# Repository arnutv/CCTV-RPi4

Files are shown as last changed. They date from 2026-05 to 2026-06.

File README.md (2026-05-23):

# CCTV-RPi4

A complete, self-hosted DIY CCTV system using **6 ESP32-CAM modules** and a **Raspberry Pi 4 or 5** as a local WiFi hub, recorder and dashboard. No cloud, no subscriptions, no router required.





---

## What it does

- **6 wireless cameras** stream MJPEG to a local Raspberry Pi
- **Motion detection** on each ESP32-CAM triggers recording (saves to RPi storage **and** each camera's local SD card simultaneously)
- **Web dashboard** accessible from any phone or laptop — 3×2 live grid, click any camera to enlarge
- **HDMI monitor** mode — Pi shows a fullscreen 3×2 grid directly on a TV (Chromium kiosk on RPi ≥ 2 GB, native pygame on RPi 1 GB)
- **Solar-powered cameras** — each camera runs on a 6V/10W panel + 2× 18650 batteries (~$27 hardware)
- **3D-printed enclosure** — parametric OpenSCAD & FreeCAD designs included
- **Adaptive install** — one script auto-detects RAM and configures the system optimally (LITE / MID / FULL modes)
- **Optional internet bridge** — `connect_router.sh` lets the RPi share your home WiFi or ethernet with the cameras

---

## Architecture

```
   ┌──────────────┐   ┌──────────────┐   ┌──────────────┐
   │ ESP32-CAM #1 │   │ ESP32-CAM #2 │   │ ESP32-CAM #N │
   │  + SD card   │   │  + SD card   │   │  + SD card   │
   │  + solar/bat │   │  + solar/bat │   │  + solar/bat │
   └──────┬───────┘   └──────┬───────┘   └──────┬───────┘
          │ MJPEG @ port 81  │                  │
          │ + frame uploads  │                  │
          └─────────┬────────┴──────────────────┘
                    │  WiFi 192.168.4.0/24 (WPA2)
                    ▼
         ┌──────────────────────────┐
         │   Raspberry Pi 4 or 5    │
         │   wlan0 = AP (.4.1)      │
         │   Flask server :8080     │
         │   ├─ /         dashboard │
         │   ├─ /display  HDMI grid │
         │   ├─ /upload   from cams │
         │   └─ /api/cameras …      │
         └──┬──────────────────┬────┘
            │ HDMI             │ optional eth0 / wlan1
            ▼                  ▼
        ┌──────┐          ┌──────────────┐
        │  TV  │          │  Home router │
        └──────┘          │  → Internet  │
                          └──────────────┘
```

---

## Hardware

### Per camera (6× total)

| Item | Spec | ~Cost |
|---|---|---|
| AI-Thinker ESP32-CAM | OV2640 sensor, ESP32-S | $8 |
| MicroSD card | 16-32 GB Class 10 | $8 |
| 6 V 10 W solar panel | 250×200 mm | $9 |
| CN3791 MPPT charger | 1S Li-ion output | $3 |
| 2× 18650 Li-ion | Samsung 30Q or similar (3000 mAh) | $8 |
| 1S BMS module | DW01A+FS8205A, 20×10 mm (over-discharge + short-circuit) | $1 |
| MT3608 boost converter | 5 V output | $1 |
| IP65 junction box | 158×90×65 mm | $6 |
| Misc (PG7 gland, lens disc, screws) | | ~$3 |
| **Subtotal per camera** | | **~$47** |

### Hub

| Item | Spec | ~Cost |
|---|---|---|
| Raspberry Pi 4 (1 GB+) or RPi 5 (2 GB+) | | $35-50 |
| Power supply | 5V/3A USB-C (Pi 4) or 5V/5A (Pi 5) | $8-13 |
| MicroSD (or USB SSD) | 32 GB+ for OS + recordings | $8 |
| Active cooler | RPi 5 only | $5 |
| micro-HDMI cable | optional, for TV display | $5 |

**Total system cost: ~$330 for 6 cameras + hub.**

---

## Quick start

### 1. Raspberry Pi setup (15 min)

Flash **Raspberry Pi OS 64-bit (Bookworm)** to your SD card with Raspberry Pi Imager. Set hostname, enable SSH, configure your wifi for first-time access.

SSH in and run:

```bash
git clone https://github.com/arnutv/CCTV-RPi4.git
cd CCTV-RPi4/rpi4
sudo bash install.sh
sudo reboot
```

The installer **auto-detects** your board and RAM, then chooses:

| Mode | Trigger | What runs |
|---|---|---|
| **LITE** | RAM < 1.5 GB | Headless, native pygame HDMI display, `gpu_mem=32` |
| **MID** | RAM 1.5-3 GB | Chromium kiosk (trimmed), `gpu_mem=64` |
| **FULL** | RAM ≥ 4 GB | Full Chromium kiosk, `gpu_mem=128` |

After reboot:
- WiFi network **`CCTV_Network`** (pass: `cctv1234!!`) — cameras join this
- Dashboard at **`http://192.168.4.1:8080/`** from phone or laptop
- HDMI shows the 3×2 grid automatically (if connected)

### 2. Flash the cameras (5 min each)

For each ESP32-CAM, edit `CCTV-Camera/cam_config.h` to set its ID and name:

```cpp
#define CAM_ID   1                  // 1-6, unique per camera
#define CAM_NAME "Front Door"       // shown in dashboard
```

Open `CCTV-Camera/CCTV-Camera.ino` in Arduino IDE:
- Board: **AI Thinker ESP32-CAM**
- ESP32 core: **1.0.6** (pinned for stability)
- Partition: **Huge APP (3MB No OTA / 1MB SPIFFS)**

Flash with a USB-to-serial adapter (GPIO0 to GND while pressing reset).

> **Tip:** the included [GitHub Actions workflow](.github/workflows/build-firmware.yml) builds the firmware in the cloud — no Arduino IDE needed. Just go to the Actions tab → "Build ESP32-CAM Firmware" → Run workflow, fill in the cam ID/name, and download the `.bin` from the artifacts.

### 3. Power & mount the cameras

Connect each camera to its solar panel + 18650 battery rig (see `enclosure/wiring.txt`). Power on — the camera auto-connects to `CCTV_Network`, gets its static IP (`192.168.4.10X` based on `CAM_ID`), and appears live on the dashboard.

---

## Web dashboard

Browse to `http://192.168.4.1:8080/` from any device on the CCTV WiFi:

- **3×2 live grid** of all cameras with status pills (LIVE / MOTION / OFFLINE)
- **Click any camera** to enlarge to a large modal with live feed, battery %, and snapshot/page buttons
- **Recordings browser** with per-camera tabs, frame-by-frame playback, save individual frames
- **Storage chips** show RPi disk free + estimated days of retention left + auto-cleanup setting
- **One-click cleanup** button to flush recordings older than the retention period (default 30 days)
- **System health** in the header: CPU temp, uptime, internet IP (if connected), disk bar

---

## HDMI display

Plug an HDMI monitor or TV into the RPi (micro-HDMI to HDMI cable for RPi 4/5).

| Mode | Renderer | RAM cost | Notes |
|---|---|---|---|
| **LITE** | `display.py` — pygame on KMSDRM | ~80 MB | Auto-installed by `install.sh` on 1 GB boards; no X server, no browser |
| **MID/FULL** | Chromium kiosk → `/display` | ~500 MB | Same look as the web dashboard, GPU-accelerated |

Exit display: `Esc` or `Q` on a keyboard, or `sudo systemctl stop cctv-display`.

---

## Optional: internet bridge

By default the RPi is an island — cameras can talk to it but not to the internet. To bridge:

```bash
# Via ethernet (cleanest)
sudo bash rpi4/connect_router.sh eth

# Via USB WiFi dongle
sudo bash rpi4/connect_router.sh wifi "HomeWiFi" "yourpassword"

# Undo
sudo bash rpi4/connect_router.sh --remove
```

Now the dashboard is also reachable from your home network (look for the IP in the dashboard header), and you can SSH in from anywhere on your LAN.

---

## Enclosure & 3D printing

Files in `enclosure/` — two formats, each part also has its own standalone file:

| File | Contents |
|---|---|
| `tray.scad` | Electronics tray — open, F6, export STL |
| `solar_bracket.scad` | Solar panel arm — open, F6, export STL |
| `cctv_enclosure.scad` | Both parts in one file (`PART = "all"` preview) |
| `cctv_enclosure.FCMacro` | FreeCAD Python macro — same 2 parts |

Designed to drop inside a **140 × 78 mm outer IP65 junction box** (typical thai weatherproof box). The lens hole and ESP32-CAM mount are drilled directly through the box's own lid.

Parts (3D-printed):

| Part | File | Print time | Filament | Purpose |
|---|---|---|---|---|
| Electronics tray | `tray.scad` | 90 min | 28 g | Holds battery + MPPT + boost inside the IP65 box |
| Solar bracket | `solar_bracket.scad` | 55 min | 20 g | L-arm screws to wall (2× M5); solar panel bolts to far end of arm (4× M4) |

**Print in PETG** (or ASA) at 0.2 mm, 4 perimeters, 25 % gyroid infill. No supports needed.

See `enclosure/wiring.txt` for the full assembly + waterproofing checklist.

---

## File layout

```
CCTV-RPi4/
├── CCTV-Camera/                 # Arduino sketch (flash this to each ESP32-CAM)
│   ├── CCTV-Camera.ino
│   ├── cam_config.h            # ← Edit CAM_ID and CAM_NAME per unit
│   ├── camera_pins.h
│   ├── motion.h
│   ├── power.h
│   ├── recorder.h
│   └── webui.h
├── rpi4/                        # Raspberry Pi server side
│   ├── install.sh              # One-shot setup (auto-adaptive LITE/MID/FULL)
│   ├── cctv_server.py          # Flask dashboard + upload endpoint
│   ├── display.py              # Native pygame HDMI display (LITE mode)
│   └── connect_router.sh       # Optional internet bridge
├── preview/                     # Browser preview of the dashboard (Windows PC)
│   ├── index.html              # Static mock dashboard
│   └── serve.ps1               # Tiny PowerShell HTTP server
├── enclosure/                   # 3D-printable parts
│   ├── tray.scad               # Electronics tray — standalone, open → F6 → STL
│   ├── solar_bracket.scad      # Solar panel arm  — standalone, open → F6 → STL
│   ├── cctv_enclosure.scad     # Combined preview (both parts, PART variable)
│   ├── cctv_enclosure.FCMacro  # FreeCAD Python macro (same 2 parts)
│   └── wiring.txt              # ASCII wiring + waterproofing notes
├── .github/workflows/
│   └── build-firmware.yml      # Cloud-builds ESP32 firmware, exports .bin
├── .gitignore
└── README.md
```

---

## Configuration cheatsheet

| What | Where | Default |
|---|---|---|
| WiFi SSID + password | `CCTV-Camera/cam_config.h` + `rpi4/install.sh` | `CCTV_Network` / `cctv1234!!` |
| Camera ID + name | `CCTV-Camera/cam_config.h` per unit | `CAM_ID 1`, `"Front Door"` |
| RPi static IP for AP | `rpi4/install.sh` | `192.168.4.1` |
| Recording retention | `rpi4/cctv_server.py` → `RETENTION_DAYS` | `30` days |
| Frame resolution | inside `CCTV-Camera.ino`: `s->set_framesize()` | `FRAMESIZE_VGA` |
| GPU memory | auto via install.sh | 32/64/128 MB |
| Server port | `rpi4/cctv_server.py` | `8080` |
| Cameras list (for dashboard) | `rpi4/cctv_server.py` → `CAMERAS` | 6 entries, edit to add/remove |

---

## Performance

Measured with **6 cameras at VGA 5 FPS, motion-triggered recording**:

| Board | Boot | CPU idle | CPU peak | RAM used | Smoothness |
|---|---|---|---|---|---|
| RPi 4 1 GB | ~25 s | 4 % | 35-45 % | ~600 MB | Adequate |
| RPi 4 2/4/8 GB | ~22 s | 3 % | 25-35 % | ~600 MB | Smooth |
| RPi 5 (2/4/8 GB) | ~12 s | 1-2 % | 12-18 % | ~700 MB | Snappy |

Cameras can scale up to **~12 units** before grid cells become too small to read on a 32" TV.

---

## Troubleshooting

| Symptom | Likely cause | Fix |
|---|---|---|
| Camera shows OFFLINE in dashboard | Bad wifi / wrong CAM_ID | Re-flash with correct config; check serial output |
| Dashboard slow / laggy | Too many concurrent viewers | Max 2-3 phones streaming full grid; close extras |
| Recordings folder filling disk | Retention too long | Lower `RETENTION_DAYS` and run "Clean now" |
| HDMI black on RPi 5 1 GB | Chromium ran out of memory | Confirm install picked LITE mode; check `systemctl status cctv-display` |
| Solar camera dies overnight | Cloudy days drained battery | Upsize to 12 V 20 W panel + LiFePO4 (see `wiring.txt` "Robust tier") |
| Lens fogged from inside | Trapped condensation | Add a PTFE breathable vent on the bottom of the IP65 box |

---

## Contributing

PRs welcome. Run the cloud build (Actions tab) before opening a PR to confirm the firmware still compiles.

---

## License

MIT — see [LICENSE](LICENSE) if present, otherwise consider this MIT-licensed.

---

## Credits

Built with `esp32-arduino`, `esp_camera`, `Flask`, `pygame`, `hostapd`, `dnsmasq` and a Raspberry Pi.

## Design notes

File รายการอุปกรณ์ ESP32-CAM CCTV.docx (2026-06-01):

รายการอุปกรณ์ ESP32-CAM CCTV

Solar Cell 6V 15W + CN3791 MPPT Charge Controller

วันที่: 23 พฤษภาคม 2026

1. หลัก / Main Components

1. ESP32-CAM AI-Thinker - With OV2640 Camera Module x1 232.46 GusTron

2. Solar Panel - 6V 15W x1 236.15 ณ ภัทร เทคโนโลยี

3. CN3791 MPPT Charge Controller - 4.5V-6V Input, 1-2A (Module) x1 91.77 ไอ.อาร์. เทคโนโลยี

4. 18650 Li-ion Battery - 3000-3500 mAh x2 27.00 Exceedbytech

5. 18650 Battery Holder - 2-Cell Parallel x1 n/a

6. MT3608 Boost Converter - 3.7V to 5V Output x1 72.46/3 ไอ.อาร์. เทคโนโลยี

7. MicroSD Card - 16GB+ Class 10 x1 n/a

8. USB-TTL Programmer - CH340 or FTDI Module x1 n/a

9. Waterproof Enclosure Box - IP65+ x1 75.00/3 NNR Home Solution

รวม 636.53

2. อุปกรณ์เสริม / Supporting Components

9. Resistor - 100k Ohm x2

10. Capacitor - 100uF 10V x1

11. Capacitor - 10uF 10V x1

12. Inductor - 10uH (สำหรับ CN3791 แบบ DIY) x1

13. Diode Schottky - 1N5819 x1

14. Waterproof Enclosure Box - IP65+ x1

15. Cable Gland - PG7 x2

16. JST Connector / Screw Terminal- - 1 ชุด

17. Jumper Wire / PCB Stripboard - - 1 ชุด

3. วงจรไฟ / Power Flow

Solar Panel 6V 15W

CN3791 MPPT <--> 2x 18650 (parallel)

(ใช้พลังงานเต็ม 15W)

MT3608 Boost Converter

5V ESP32-CAM

GPIO33 <-- Voltage Divider (100k+100k) <-- Battery+

4. CN3791 vs TP4056 เปรียบเทียบ

ชาร์จสูงสุด : TP4056 = 1A | CN3791 = 2A

MPPT : TP4056 = ไม่มี | CN3791 = มี

ใช้พลังงาน Panel : TP4056 = ~40% | CN3791 = ~95%

ราคา : TP4056 = ถูก | CN3791 = แพงกว่านิดหน่อย

ต้องการ Inductor : TP4056 = ไม่ | CN3791 = ใช่ (ถ้า DIY)

5. หมายเหตุ / Notes

* CN3791 แบบ Module สำเร็จรูป มี Inductor และ Diode ติดมาแล้ว แนะนำซื้อแบบ Module

* TP4056 ชาร์จได้สูงสุด 1A แม้ Panel จะให้ 2.5A ทำให้เสียพลังงาน ~60%

* CN3791 ใช้ MPPT ดึงพลังงานจาก Panel ได้เกือบ 100%

* 2x 18650 ต่อ Parallel ให้ความจุรวม ~6000-7000 mAh รองรับกลางคืน ~20-23 ชั่วโมง

* MT3608 Boost Converter แปลง 3.7V (แบต) เป็น 5V สำหรับ ESP32-CAM

* GPIO33 + Voltage Divider (100k+100k) ใช้วัดระดับแบตเตอรี่ใน firmware

* แนะนำ MicroSD Class 10 ขึ้นไป รองรับการบันทึก JPEG ต่อเนื่อง ~5fps

สร้างโดย Claude Code | ESP32-CAM CCTV Project | 23 พฤษภาคม 2026

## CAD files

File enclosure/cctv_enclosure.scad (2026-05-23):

// ═══════════════════════════════════════════════════════════════════════════
//  CCTV-Camera — Enclosure parts (combined preview file)
//  For single-part STL export use the individual files:
//    tray.scad           — Electronics tray  (open → F6 → Export STL)
//    solar_bracket.scad  — Solar panel arm   (open → F6 → Export STL)
//
//  This file lets you preview both parts together or pick one with PART.
//  All dimensions in mm. Print in PETG (preferred) or PLA+.
// ═══════════════════════════════════════════════════════════════════════════

// ─── PICK ONE PART TO RENDER ──────────────────────────────────────────────
PART = "all";   // "tray" | "solar_bracket" | "all"

// ─── IP65 BOX INNER DIMENSIONS ────────────────────────────────────────────
BOX_W = 134;   // inside width  (140 mm outer − 2×3 mm walls)
BOX_D =  72;   // inside depth  ( 78 mm outer − 2×3 mm walls)

// ─── ELECTRONICS (real measured sizes, mm) ────────────────────────────────
HOLDER_W = 75;  HOLDER_D = 36;
CN3791_W = 30;  CN3791_D = 20;
MT3608_W = 36;  MT3608_D = 17;
BMS_W    = 20;  BMS_D    = 10;   // 1S BMS (DW01A+FS8205A, 20×10 mm)

// ─── SOLAR BRACKET ────────────────────────────────────────────────────────
ARM_L   = 80;
ARM_W   = 25;
ARM_TH  =  4;
PLATE_H = 100;

// ─── PRINT TOLERANCES ─────────────────────────────────────────────────────
WALL = 1.6;
SLOP = 0.3;
$fn = 64;

// ═══════════════════════════════════════════════════════════════════════════
//                                 PARTS
// ═══════════════════════════════════════════════════════════════════════════

// ─── Helper: PCB clip ─────────────────────────────────────────────────────
module pcb_clip(pcb_w, pcb_d, h) {
    difference() {
        cube([pcb_w + WALL*2 + SLOP*2, pcb_d + WALL*2 + SLOP*2, h]);
        translate([WALL, WALL, 1.6])
            cube([pcb_w + SLOP*2, pcb_d + SLOP*2, h]);
        translate([(pcb_w + WALL*2)/2 - 6, -1, 3])
            cube([12, pcb_d + WALL*4 + SLOP*2 + 2, h]);
    }
}

// ─── 1. ELECTRONICS TRAY ──────────────────────────────────────────────────
module electronics_tray() {
    difference() {
        union() {
            cube([BOX_W - 4, BOX_D - 4, 2]);

            translate([4, 4, 2])
                difference() {
                    cube([HOLDER_W + SLOP*2, HOLDER_D + SLOP*2, 8]);
                    translate([WALL, WALL, 2])
                        cube([HOLDER_W + SLOP*2 - WALL*2,
                              HOLDER_D + SLOP*2 - WALL*2, 10]);
                }

            // Right column: MPPT (top) → Boost (middle) → BMS (bottom)
            translate([4 + HOLDER_W + 6, 4, 2])
                pcb_clip(CN3791_W, CN3791_D, 6);

            translate([4 + HOLDER_W + 6, 4 + CN3791_D + 5, 2])
                pcb_clip(MT3608_W, MT3608_D, 6);

            translate([4 + HOLDER_W + 6, 4 + CN3791_D + 5 + MT3608_D + 5, 2])
                pcb_clip(BMS_W, BMS_D, 6);

            for (x = [10, BOX_W - 14], y = [10, BOX_D - 14])
                translate([x, y, 2]) cylinder(d=4, h=12);
        }

        for (x = [6, BOX_W - 10], y = [6, BOX_D - 10])
            translate([x, y, -1]) cylinder(d=3.4, h=5);
    }
}

// ─── 2. SOLAR BRACKET ─────────────────────────────────────────────────────
module solar_bracket() {
    // Vertical wall plate
    difference() {
        cube([ARM_W, ARM_TH, PLATE_H]);
        for (z = [15, PLATE_H - 15]) {
            translate([ARM_W/2, -1, z])
                rotate([-90, 0, 0])
                    cylinder(d=5.5, h=ARM_TH + 2);
            translate([ARM_W/2, -0.1, z])
                rotate([-90, 0, 0])
                    cylinder(d1=10.5, d2=5.5, h=3.2);
        }
    }

    // Horizontal arm
    translate([0, ARM_TH, PLATE_H - ARM_TH])
        difference() {
            cube([ARM_W, ARM_L, ARM_TH]);
            // 4× M4 panel mounting holes near far end
            for (xp = [5, ARM_W - 5], yp = [ARM_L - 20, ARM_L - 8])
                translate([xp, yp, -1])
                    cylinder(d=4.5, h=ARM_TH + 2);
        }

    // Triangular gusset
    translate([0, ARM_TH, PLATE_H - ARM_TH])
        rotate([0, -90, 0])
            linear_extrude(ARM_W)
                polygon([[0, 0], [25, 0], [0, -25]]);
}

// ═══════════════════════════════════════════════════════════════════════════
//                            LAY OUT FOR EXPORT
// ═══════════════════════════════════════════════════════════════════════════
if      (PART == "tray")           electronics_tray();
else if (PART == "solar_bracket")  solar_bracket();
else {
    // "all" — both parts side by side for preview
    electronics_tray();
    translate([BOX_W + 30, 0, 0]) solar_bracket();
}

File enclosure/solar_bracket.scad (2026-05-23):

// ═══════════════════════════════════════════════════════════════════════════
//  Solar Bracket  —  standalone part file
//  L-shaped wall arm for mounting a 6V/10W solar panel.
//
//  Geometry:
//    Vertical wall plate  25 × 4 × 100 mm   — screws to wall (2× M5)
//    Horizontal arm       25 × 80 × 4 mm    — panel rests on top
//    Triangular gusset                       — prevents arm from drooping
//    Panel mounting holes  4× M4 at arm end — bolts through panel frame
//
//  Open in OpenSCAD → F6 → File → Export → STL
//  Print in PETG (preferred for UV/outdoor) at 0.2 mm layers,
//  4 perimeters, 40 % gyroid infill. No supports needed.
// ═══════════════════════════════════════════════════════════════════════════

ARM_L   = 80;    // horizontal arm length (mm)
ARM_W   = 25;    // arm + plate width     (mm)
ARM_TH  =  4;    // arm + plate thickness (mm)
PLATE_H = 100;   // vertical plate height (mm)

$fn = 64;

module solar_bracket() {
    // ── Vertical wall plate ──────────────────────────────────────────────
    difference() {
        cube([ARM_W, ARM_TH, PLATE_H]);
        // 2× M5 wall-screw holes (⌀5.5), countersunk on the back face
        for (z = [15, PLATE_H - 15]) {
            translate([ARM_W/2, -1, z])
                rotate([-90, 0, 0])
                    cylinder(d=5.5, h=ARM_TH + 2);
            translate([ARM_W/2, -0.1, z])
                rotate([-90, 0, 0])
                    cylinder(d1=10.5, d2=5.5, h=3.2);   // 90° countersink
        }
    }

    // ── Horizontal arm (extends outward from top of plate) ───────────────
    translate([0, ARM_TH, PLATE_H - ARM_TH])
        difference() {
            cube([ARM_W, ARM_L, ARM_TH]);
            // 4× M4 panel mounting holes (⌀4.5) near the far end of arm
            for (xp = [5, ARM_W - 5], yp = [ARM_L - 20, ARM_L - 8])
                translate([xp, yp, -1])
                    cylinder(d=4.5, h=ARM_TH + 2);
        }

    // ── Triangular gusset (joins underside of arm to plate) ─────────────
    translate([0, ARM_TH, PLATE_H - ARM_TH])
        rotate([0, -90, 0])
            linear_extrude(ARM_W)
                polygon([[0, 0], [25, 0], [0, -25]]);
}

solar_bracket();

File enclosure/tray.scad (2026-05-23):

// ═══════════════════════════════════════════════════════════════════════════
//  Electronics Tray  —  standalone part file
//  Sits inside the IP65 junction box and holds battery + MPPT + boost
//  converter + BMS in fixed positions (no rattling).
//
//  Circuit flow:
//    Solar → CN3791 (MPPT charge) → 18650 × 2 → BMS (discharge protect)
//    → MT3608 (boost 5 V) → ESP32-CAM
//
//  Open in OpenSCAD → F6 → File → Export → STL
//  Print in PETG (preferred) or PLA+ at 0.2 mm layers, 4 perimeters,
//  25 % gyroid infill. No supports needed.
// ═══════════════════════════════════════════════════════════════════════════

// ─── IP65 BOX INNER DIMENSIONS ────────────────────────────────────────────
// Default for 140 × 78 mm outer junction box (typical thai weatherproof box):
//   140 - 2×3 mm walls = 134 mm inner length
//    78 - 2×3 mm walls =  72 mm inner depth
// Edit to match your box (always use INNER measurements).
BOX_W = 134;   // inside width  (lengthwise)
BOX_D =  72;   // inside depth  (top → bottom mounted)

// ─── ELECTRONICS (real measured sizes, mm) ────────────────────────────────
HOLDER_W = 75;  HOLDER_D = 36;   // 2× 18650 battery holder footprint
CN3791_W = 30;  CN3791_D = 20;   // CN3791 MPPT charger PCB
MT3608_W = 36;  MT3608_D = 17;   // MT3608 boost converter PCB
BMS_W    = 20;  BMS_D    = 10;   // 1S BMS module (DW01A+FS8205A, 20×10 mm)

// ─── PRINT TOLERANCES ─────────────────────────────────────────────────────
WALL = 1.6;   // wall thickness (4 perimeters @ 0.4 mm nozzle)
SLOP = 0.3;   // fit clearance
$fn = 64;

// Column X offset shared by MPPT, Boost, BMS clips
COL_X = 4 + HOLDER_W + 6;   // = 85 mm from tray left edge

// ═══════════════════════════════════════════════════════════════════════════

// PCB clip — two L-shaped fingers that grip a small PCB by its edges.
// A centre window lets you lift the PCB out without tools.
module pcb_clip(pcb_w, pcb_d, h) {
    difference() {
        cube([pcb_w + WALL*2 + SLOP*2, pcb_d + WALL*2 + SLOP*2, h]);
        translate([WALL, WALL, 1.6])
            cube([pcb_w + SLOP*2, pcb_d + SLOP*2, h]);
        translate([(pcb_w + WALL*2)/2 - 6, -1, 3])
            cube([12, pcb_d + WALL*4 + SLOP*2 + 2, h]);
    }
}

// Main tray
module electronics_tray() {
    difference() {
        union() {
            // Base plate
            cube([BOX_W - 4, BOX_D - 4, 2]);

            // Battery holder pocket (open box around holder, left side)
            translate([4, 4, 2])
                difference() {
                    cube([HOLDER_W + SLOP*2, HOLDER_D + SLOP*2, 8]);
                    translate([WALL, WALL, 2])
                        cube([HOLDER_W + SLOP*2 - WALL*2,
                              HOLDER_D + SLOP*2 - WALL*2, 10]);
                }

            // MPPT charger clip (right column, top)
            translate([COL_X, 4, 2])
                pcb_clip(CN3791_W, CN3791_D, 6);

            // Boost converter clip (right column, middle)
            translate([COL_X, 4 + CN3791_D + 5, 2])
                pcb_clip(MT3608_W, MT3608_D, 6);

            // BMS clip (right column, bottom — under boost)
            translate([COL_X, 4 + CN3791_D + 5 + MT3608_D + 5, 2])
                pcb_clip(BMS_W, BMS_D, 6);

            // Cable routing posts at 4 corners
            for (x = [10, BOX_W - 14], y = [10, BOX_D - 14])
                translate([x, y, 2]) cylinder(d=4, h=12);
        }

        // M3 screw holes (align with standoffs inside the IP65 box)
        for (x = [6, BOX_W - 10], y = [6, BOX_D - 10])
            translate([x, y, -1]) cylinder(d=3.4, h=5);
    }
}

electronics_tray();

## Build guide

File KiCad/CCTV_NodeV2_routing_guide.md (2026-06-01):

# CCTV_NodeV2 — PCB routing guide

The schematic (`CCTV_NodeV2.kicad_sch`) and the PCB (`CCTV_NodeV2.kicad_pcb`) are both checked in. The PCB has all 9 components placed on a 100 × 80 mm 2-layer board with **every net assigned to its correct pad**. What's missing are the **copper traces** — the colored airwires you see in pcbnew.

KiCad 10 ships **without a built-in autorouter**. You have two routes from "ratsnest" to "fully routed board":

| Path | Time | Quality | Effort |
|---|---|---|---|
| **A. Interactive routing in pcbnew** | 15–30 min | excellent | manual, learn the X tool |
| **B. Freerouting (external)** | 2–5 min | good, sometimes messy | one-time download |

---

## A. Interactive routing (recommended for small boards)

1. Open `KiCad/CCTV_NodeV2.kicad_pcb` in KiCad → pcbnew opens.
2. Press **`B`** to refresh the ratsnest — colored thin lines now connect pads that share a net.
3. Press **`X`** to start the **interactive router**.
4. Click a pad (or hover over a ratsnest line and click), drag, and click again to lay each segment. Press **`V`** to drop a via to the other copper layer when you need to cross a trace.
5. Press **`Esc`** to finish a route, then click the next net.
6. When all airwires are gone you're done. **Run DRC** (`Inspect → Design Rules Checker`) to catch any clearance issues.

Order I'd recommend:
- **Power first** (`+5V`, `+3V3`, `BATT+`, `GND`, `SOLAR+/-`, `BATT-`, `PROT-` — wait, this PCB consolidates to `GND`)
- **Camera control** next (`SIOC`, `SIOD`, `VSYNC`, `HREF`, `PCLK`, `XCLK`)
- **Camera data bus last** (`CAM_D0..D7`) — these are the 8 lines that run from U4 right side to U5 right side; expect to use a couple of vias to drop through the board

---

## B. Freerouting (one-click autorouter)

### One-time setup

1. **Install Java 17 or later** if you don't have it. Test with `java -version` in a terminal — should print something with `17.x` or higher.
   - Windows: download the LTS JDK from https://adoptium.net/
2. **Download Freerouting**:
   - Go to https://github.com/freerouting/freerouting/releases
   - Grab the latest `freerouting-X.Y.Z.jar`
   - Save it somewhere stable, e.g. `C:\Tools\freerouting.jar`

### Each time you want to autoroute

1. In pcbnew with `CCTV_NodeV2.kicad_pcb` open:
   - **File → Export → Specctra DSN…**
   - Save as `CCTV_NodeV2.dsn` next to your PCB file.
2. Open a terminal in the same folder and run:
   ```powershell
   java -jar C:\Tools\freerouting.jar -de CCTV_NodeV2.dsn -do CCTV_NodeV2.ses
   ```
   - `-de` = design (input)
   - `-do` = output session
   - Freerouting will route in headless mode for a few minutes; you'll see progress in the terminal. For interactive mode (GUI), drop the `-do` flag.
3. Back in pcbnew:
   - **File → Import → Specctra Session…**
   - Pick `CCTV_NodeV2.ses`. KiCad lays down all the traces.
4. Press **`B`** to refresh ratsnest — there should be no airwires left.
5. **Run DRC** to verify clearance.

### If Freerouting struggles

- Add **net classes** before exporting: `File → Board Setup → Net Classes`. Make a "Power" class with wider traces (e.g. 0.5 mm) for `+5V`, `+3V3`, `BATT+`, `GND`, and keep default (~0.25 mm) for signals.
- Increase board size: `Edit → Properties` of the Edge.Cuts rectangle, expand to 110 × 90 if needed.
- Re-run with the `-mp <passes>` flag for more optimization, e.g. `-mp 100`.

---

## Current component placement

The PCB ships with this layout. Move things in pcbnew (`M` key) if you don't like it — the routing happens after placement so you can always re-route.

| Ref | Component | Position (mm) | Rotation | Notes |
|---|---|---|---|---|
| J1 | Solar input (2-pin header) | (10, 12) | 90° | top-left, wires up to solar panel |
| U1 | CN3791 MPPT | (35, 12) | 0° | next to J1 |
| U2 | 1S BMS DW01A+FS8205A | (62, 12) | 0° | top-right of power chain |
| J2 | Battery pack connector (2-pin) | (10, 28) | 90° | left side, wires to 18650 pack |
| U3 | MT3608 boost | (62, 28) | 0° | below U2, +5V output goes south to U4 |
| R1 | 4.7 kΩ SIOD pull-up | (40, 38) | 90° | between MT3608 and U4 |
| R2 | 4.7 kΩ SIOC pull-up | (50, 38) | 90° | next to R1 |
| U4 | ESP32-S3-DevKitC-1 | (30, 55) | 0° | bottom-center, USB-C marker pointing up |
| U5 | OV7670 camera module | (70, 55) | 0° | bottom-right, lens marker at center |

Board outline: 0,0 to 100,80 mm rectangle on Edge.Cuts.

---

## What's already routed

The PCB ships **fully routed** — 96 trace segments covering all 21 nets:
- 18 power traces at 1 mm width on F.Cu (BATT+, BATT-, +5V, +3V3, SOLAR+, SOLAR-, partial GND)
- 38 signal + auxiliary power traces at 0.7 mm width on F.Cu (camera control + GND chain + J2 routes on B.Cu)
- 40 camera data traces at 0.7 mm width on B.Cu (CAM_D0..D7, 5 segments each in a switching pattern)

Open in pcbnew and press `B` — the ratsnest should be empty (no airwires).

| Net | Status | Notes |
|---|---|---|
| `SOLAR+` | ✅ done (1 mm F.Cu) | J1.1 → U1.1, diagonal |
| `SOLAR-` | ✅ done (1 mm F.Cu) | J1.2 → U1.2, 2-segment L |
| `BATT+` | ✅ done (1 mm F.Cu + 0.7 mm B.Cu) | Top rail at y=5 + J2.1 via left edge on B.Cu through y=8 |
| `BATT-` | ✅ done (1 mm F.Cu + 0.7 mm B.Cu) | U1.4 → U2.2 + J2.2 via left edge on B.Cu through y=16 |
| `+5V` | ✅ done (1 mm F.Cu) | U3.3 → U4.1 via right side and underbelly at y=40 |
| `+3V3` | ✅ done (1 mm + 0.7 mm F.Cu) | U4.3 → R1 → R2 → U5.1 (U4.3 exit via y=49.92 west-east then up around R1) |
| `GND` | ✅ done (0.7 mm F.Cu) | U2.4 → right edge (x=75) → U3.4 → down through OV7670 body → U5.2 + U5.4 bypass + U4.2 horizontal |
| Camera control: `SIOC`, `SIOD`, `VSYNC`, `HREF`, `PCLK`, `XCLK` | ✅ done (0.7 mm F.Cu) | Each routed as L-shape from U4 left column to U5 left column through inter-column gap |
| Camera data (`CAM_D0..D7`) | ✅ done (0.7 mm B.Cu) | All 8 lines routed on the back copper layer with a 5-segment switching pattern: exit U4 east, drop south to a unique bottom rail (y=68–76.4, 1.2 mm pitch), traverse east past U5, climb north to target y, into U5 right pad from the east. No vias needed (through-hole pads bridge layers). |

All nets are routed. If you want to verify or improve:
- Open in pcbnew, press `B` to refresh ratsnest — should be empty
- Run DRC (`Inspect → Design Rules Checker`) — expect ~6 clearance warnings at U4's right pad column (see DRC notes below)
- If desired, run Freerouting on the same DSN export — it will re-optimize the layout (typically tightening corners and reducing total trace length 10–20%)

### DRC notes for the hand-routed traces

Most traces pass between header pads at the standard 2.54 mm pitch. With 0.7 mm trace width + 1.7 mm pad diameter, the trace-to-pad clearance through the gap is **~0.07 mm** — KiCad's default 0.2 mm clearance rule will flag these.

To resolve, in **File → Board Setup → Constraints**:
- Set "Minimum clearance" to 0.1 mm (industry minimum for most fabs)
- Or reduce just the affected traces to 0.5 mm width and clearance stays at 0.2 mm
- Or accept the DRC violations if you're hand-soldering (the pads still fit, the traces just sit closer than the design rule prefers)

## Net summary (21 nets + GND)

Power: `SOLAR+`, `SOLAR-`, `BATT+`, `BATT-`, `GND`, `+5V`, `+3V3`
Camera I²C/control: `SIOD`, `SIOC`, `VSYNC`, `HREF`, `PCLK`, `XCLK`
Camera data: `CAM_D0`, `CAM_D1`, …, `CAM_D7`

> Note: the PCB consolidates the schematic's `PROT-` net into `GND` (they're electrically the same node — BMS P- and chip grounds tied together). If you re-run `Update PCB from Schematic` (F8), KiCad will flag this; either accept the merge or update the schematic to use `GND` everywhere downstream of the BMS.

---

## Manufacturing checklist (when ready)

- [ ] DRC passes (zero errors)
- [ ] Run `File → Plot…` → Gerbers + drill files
- [ ] Upload zip to JLCPCB / PCBWay / OSHPark
- [ ] Order 2-layer, 1.6 mm thickness, HASL or ENIG finish, standard FR-4
- [ ] Order matching stencil if you're doing reflow (not needed — all through-hole on this board)

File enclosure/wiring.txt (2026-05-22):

CCTV-Camera Wiring Diagram  (Recommended tier:  6V/10W panel + 2× 18650)
═══════════════════════════════════════════════════════════════════════════

                              ┌────────────────────┐
                              │   6V / 10W SOLAR   │
                              │   panel  (mounted  │
                              │   above box on     │
                              │   L-bracket)       │
                              └─────────┬──────────┘
                                        │  red(+) / black(−)
                                        │  ~30 cm cable
                                        │
                              [PG7 cable gland in box top]
                                        │
                                        ▼
                            ┌───────────────────────┐
                            │  CN3791 MPPT Charger  │
                            │   IN+   IN−   OUT+/−  │
                            │   ●─────●─────●──●    │
                            └───────────────────────┘
                                              │ │
                                              ▼ ▼
                            ┌───────────────────────┐
                            │  2× 18650 in PARALLEL │
                            │   3.0–4.2 V  6000 mAh │
                            │ (+) ────────────── (−)│
                            └───────────────────────┘
                                              │ │
                                              ▼ ▼
                            ┌───────────────────────┐
                            │  MT3608 Boost → 5 V   │
                            │   IN+   IN−   OUT+/−  │
                            │     adjust pot to 5.0V│
                            │     BEFORE connecting │
                            │     the ESP32!        │
                            └─────────┬─────────────┘
                                      │ 5 V  +  GND
                                      ▼
                            ┌───────────────────────┐
                            │     ESP32-CAM         │
                            │   5V  GND  U0R  U0T   │
                            │   ●   ●     ─   ─     │
                            │  (use 5V pin, NOT 3V) │
                            │                       │
                            │   SD card slot:       │
                            │   ┌───────┐           │
                            │   │ 16 GB │           │
                            │   └───────┘           │
                            └───────────────────────┘
                                      │
                                      └──→ Camera lens (front of box,
                                            sealed with O-ring + clear disc)

                            ┌───────────────────────┐
                            │   SMA antenna (side)  │
                            │   2.4 GHz 2 dBi omni  │
                            │   ↑ extends WiFi      │
                            │     range ~3×         │
                            └───────────────────────┘
                            (solder pigtail to ESP32-CAM
                             U.FL pad — see notes below)

WIRE GAUGE & LENGTHS
─────────────────────
  Solar → MPPT     :  20 AWG, 30 cm    (any colour, polarity matters)
  MPPT → Battery   :  20 AWG, 5 cm     (RED to +, BLACK to −)
  Battery → Boost  :  20 AWG, 5 cm
  Boost → ESP32    :  22 AWG, 8 cm     (twist pair to reduce noise)

OPTIONAL ADD-ONS
─────────────────────
  Power LED        :  3 mm green, 1 kΩ resistor, across 5 V rail.
                       Visible through 3 mm hole next to lens.
  Reset button     :  Tactile switch from ESP32-CAM RST to GND,
                       through a 6 mm waterproof button in the box side.
  Battery cut-off  :  1S BMS protection module BETWEEN battery and boost.
                       Stops over-discharge below 2.5 V (saves 18650 cells).
  External antenna :  Cut the 0Ω resistor on ESP32-CAM near U.FL connector
                       (re-route from PCB antenna to U.FL → SMA pigtail).

WATERPROOFING CHECKLIST
─────────────────────
  □  IP65 box lid has rubber gasket — don't lose it
  □  PG7 cable gland on top, tightened with O-ring (silicone seal too)
  □  Lens disc glued to bezel with clear silicone (5 mm bead all round)
  □  SMA antenna connector has rubber washer + nut tight
  □  Box mounted with cable openings facing DOWN (drip away from gland)
  □  Add a 3 mm "weep hole" on the bottom for condensation, covered
     with breathable PTFE membrane sticker (Gore vent ~$0.50 each)

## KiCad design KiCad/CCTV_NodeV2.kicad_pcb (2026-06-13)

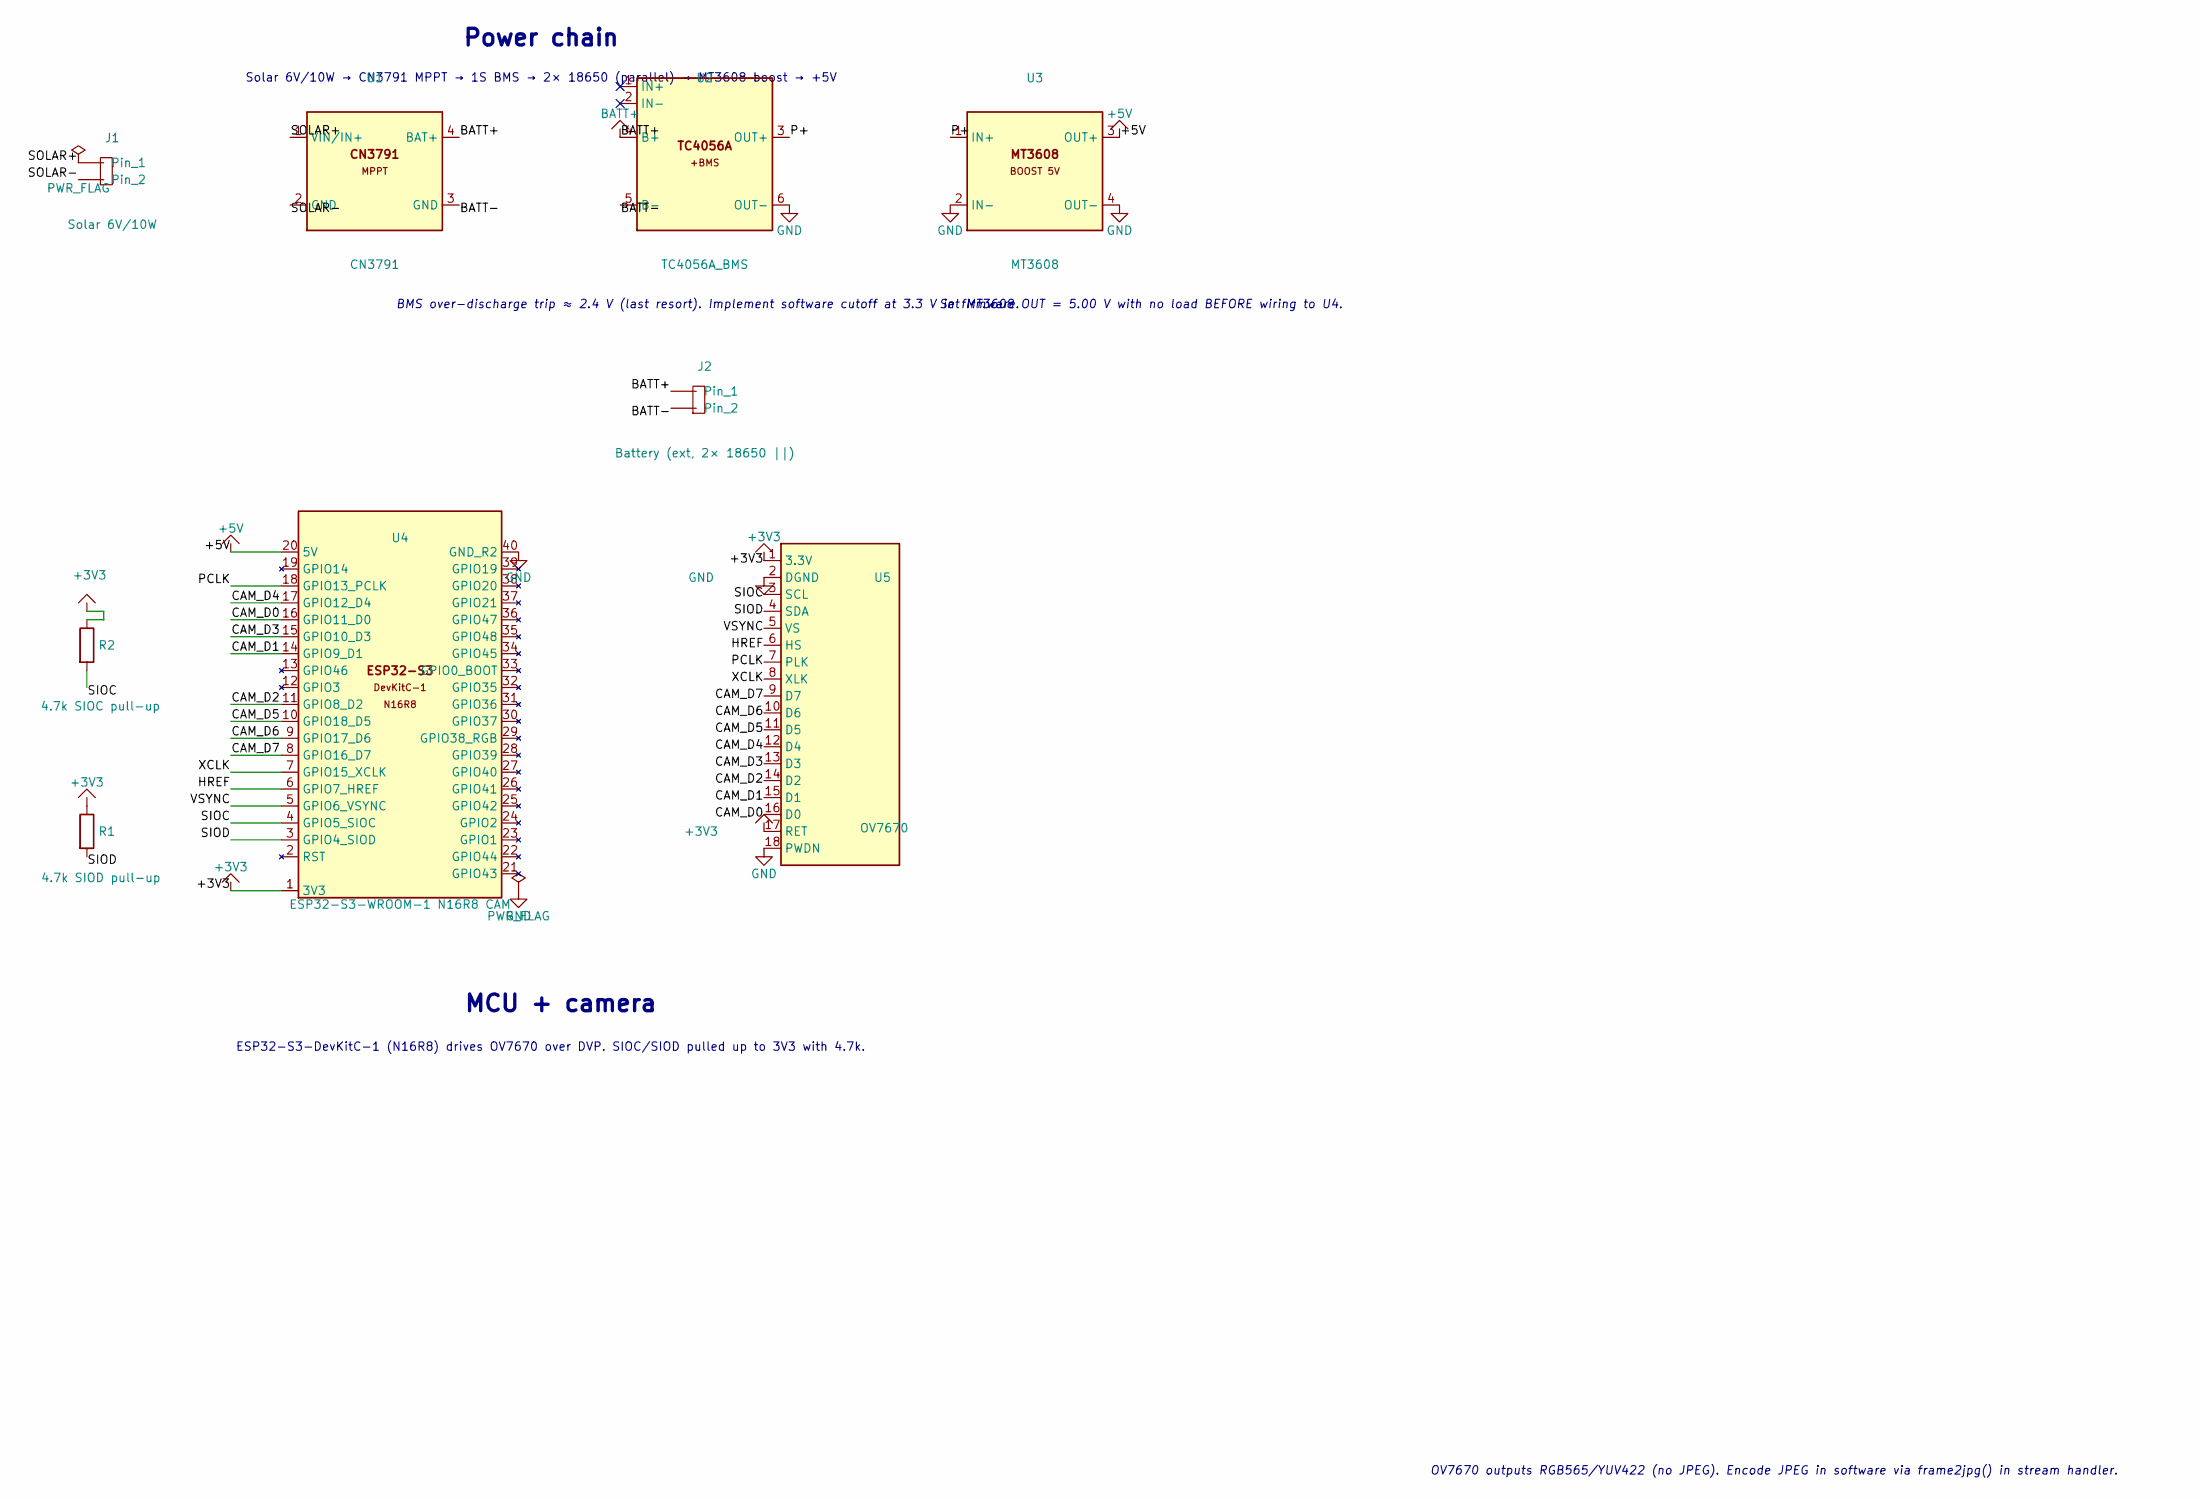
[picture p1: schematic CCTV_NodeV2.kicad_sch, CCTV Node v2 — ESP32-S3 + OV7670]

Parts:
J1: Solar 6V/10W; PinHeader_1x02_P2.54mm_Vertical
J2: Battery (ext, 2× 18650 ||); PinHeader_1x02_P2.54mm_Vertical
R1: 4.7k SIOD pull-up; R_Axial_DIN0207_L6.3mm_D2.5mm_P7.62mm_Horizontal
R2: 4.7k SIOC pull-up; R_Axial_DIN0207_L6.3mm_D2.5mm_P7.62mm_Horizontal
U1: CN3791; CN3791_Module
U2: TC4056A_BMS; TC4056A_BMS_Module
U3: MT3608; MT3608_Module
U4: ESP32-S3-WROOM-1 N16R8 CAM; ESP32-S3-CAM-N16R8_2x20_P2.54mm
U5: OV7670; OV7670_Module

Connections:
+3V3: R1.1, R2.1, U4.1 (3V3_1), U5.1 (3V3), U5.17 (RESET)
+5V: U3.3 (OUT+), U4.20 (5V_21)
/BATT-: J2.2, U1.3 (GND), U2.5 (B-)
/CAM_D0: U4.16 (GPIO11_D0_17), U5.16 (D0)
/CAM_D1: U4.14 (GPIO9_D1_15), U5.15 (D1)
/CAM_D2: U4.11 (GPIO8_D2_12), U5.14 (D2)
/CAM_D3: U4.15 (GPIO10_D3_16), U5.13 (D3)
/CAM_D4: U4.17 (GPIO12_D4_18), U5.12 (D4)
/CAM_D5: U4.10 (GPIO18_D5_11), U5.11 (D5)
/CAM_D6: U4.9 (GPIO17_D6_10), U5.10 (D6)
/CAM_D7: U4.8 (GPIO16_D7_9), U5.9 (D7)
/HREF: U4.6 (GPIO7_HREF_7), U5.6 (HREF)
/P+: U2.3 (OUT+), U3.1 (IN+)
/PCLK: U4.18 (GPIO13_PCLK_19), U5.7 (PCLK)
/SIOC: R2.2, U4.4 (GPIO5_SIOC_5), U5.3 (SIOC)
/SIOD: R1.2, U4.3 (GPIO4_SIOD_4), U5.4 (SIOD)
/SOLAR+: J1.1, U1.1 (VIN/IN+)
/SOLAR-: J1.2, U1.2 (GND)
/VSYNC: U4.5 (GPIO6_VSYNC_6), U5.5 (VSYNC)
/XCLK: U4.7 (GPIO15_XCLK_8), U5.8 (XCLK)
BATT+: J2.1, U1.4 (BAT+), U2.4 (B+)

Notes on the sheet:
Power chain
Solar 6V/10W → CN3791 MPPT → 1S BMS → 2× 18650 (parallel) → MT3608 boost → +5V
MCU + camera
ESP32-S3-DevKitC-1 (N16R8) drives OV7670 over DVP. SIOC/SIOD pulled up to 3V3 with 4.7k.
Set MT3608 OUT = 5.00 V with no load BEFORE wiring to U4.
BMS over-discharge trip ≈ 2.4 V (last resort). Implement software cutoff at 3.3 V in firmware.
OV7670 outputs RGB565/YUV422 (no JPEG). Encode JPEG in software via frame2jpg() in stream handler.

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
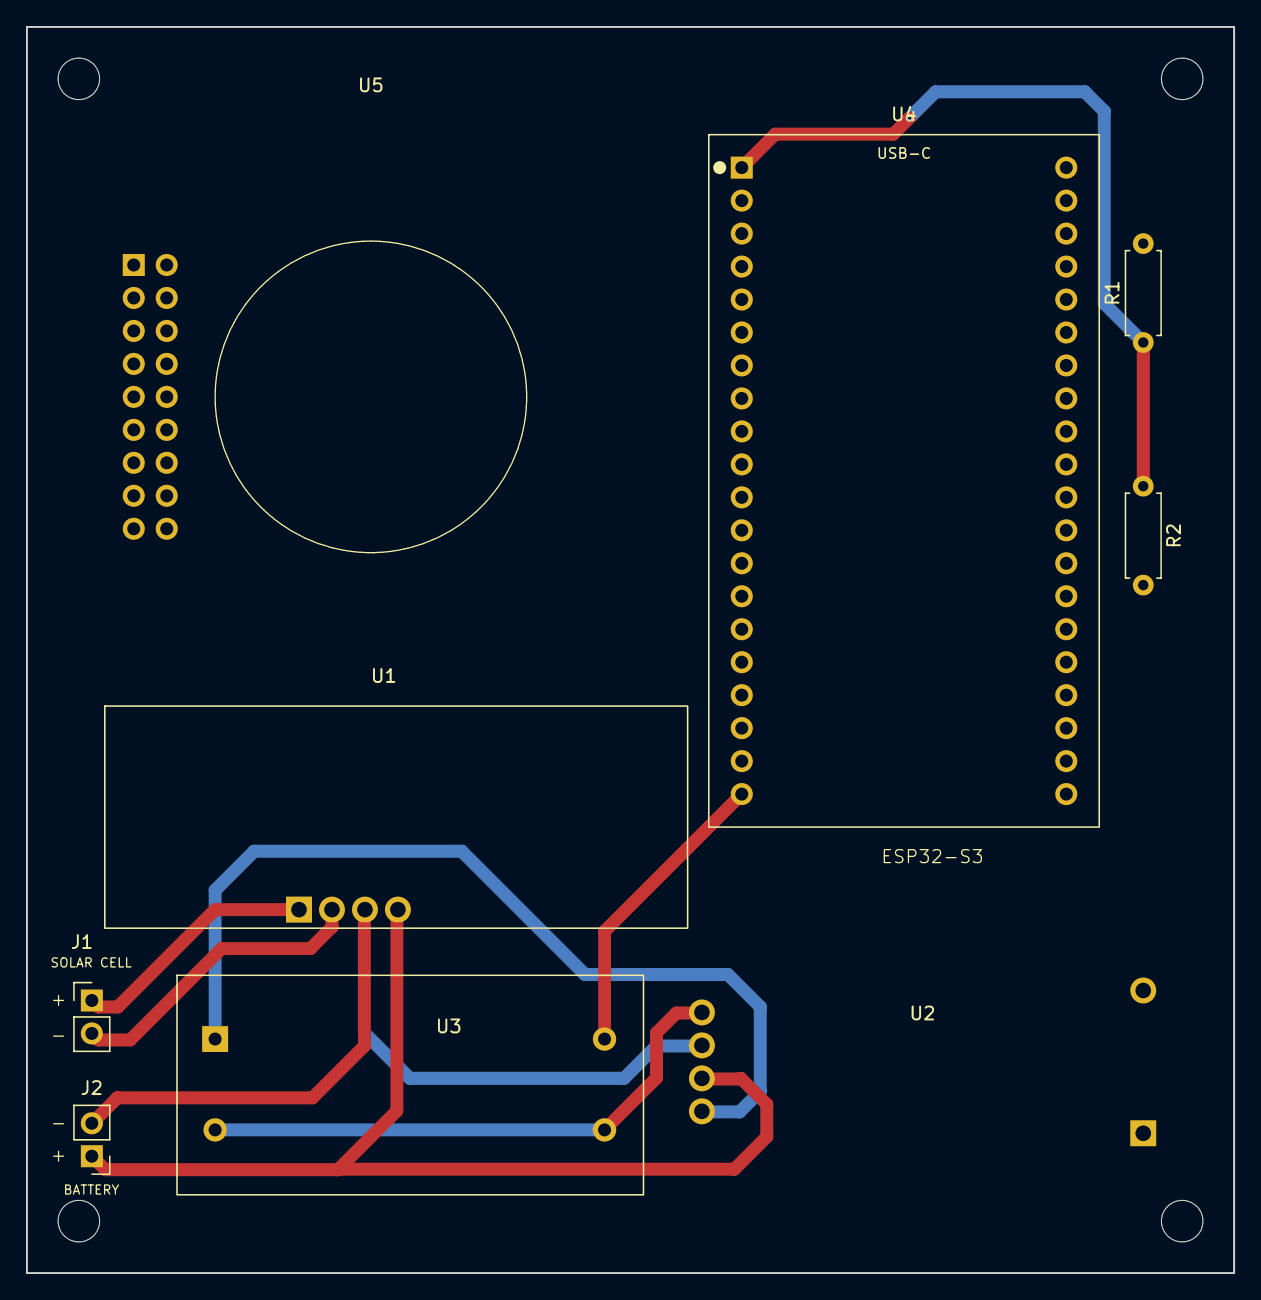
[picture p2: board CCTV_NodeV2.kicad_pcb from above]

Board: 2 copper layers, 93.0 x 96.0 mm, 9 parts (0 on the bottom side), 23 nets.

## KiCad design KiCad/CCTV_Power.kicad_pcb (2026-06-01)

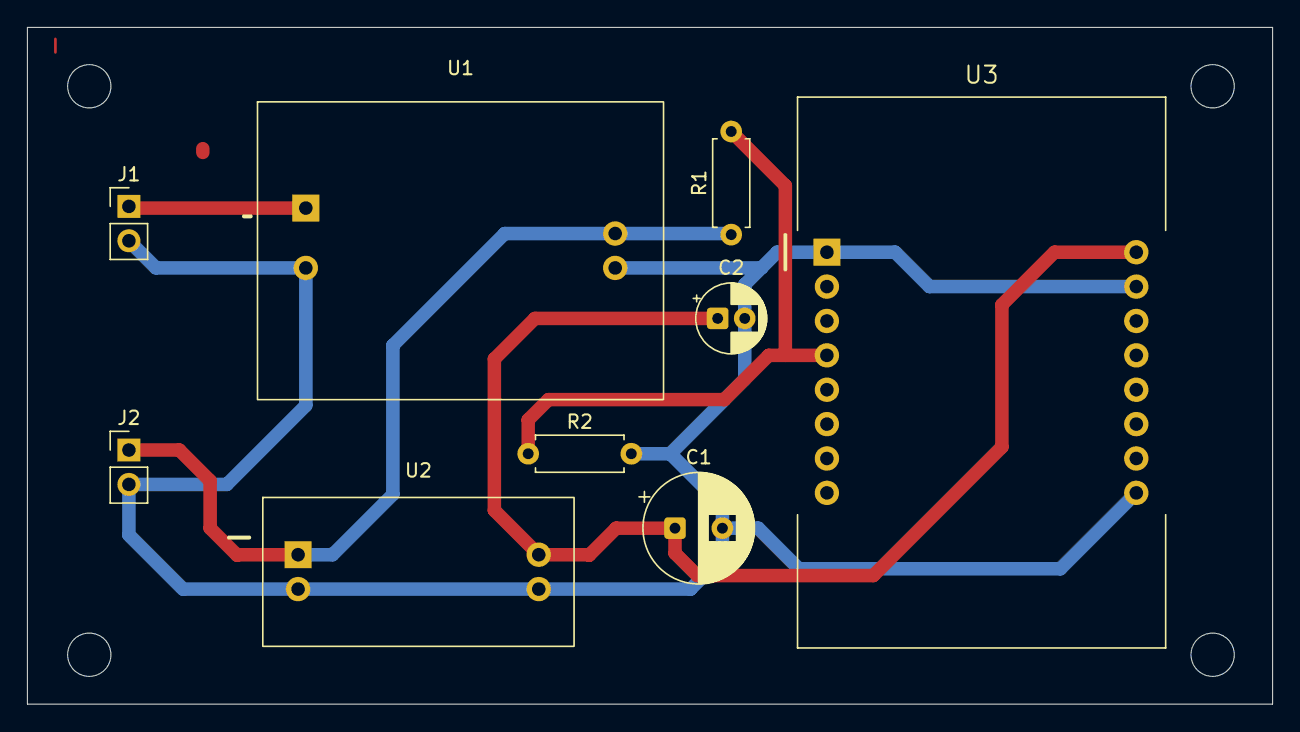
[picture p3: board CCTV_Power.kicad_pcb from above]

Board: 2 copper layers, 92.0 x 50.0 mm, 9 parts (0 on the bottom side), 5 nets.

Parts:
C1: 100uF_10V; CP_Radial_D8.0mm_P3.50mm
C2: 10uF_10V; CP_Radial_D5.0mm_P2.00mm
J1: Solar_Input; PinHeader_1x02_P2.54mm_Vertical
J2: Battery_Conn; PinHeader_1x02_P2.54mm_Vertical
R1, R2: 100k; R_Axial_DIN0207_L6.3mm_D2.5mm_P7.62mm_Horizontal
U1: CN3791_Module
U2: MT3608_Module
U3: ESP32-CAM; ESP32-CAM_AI-Thinker

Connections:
+5V: C1.1, C2.1, U2.3, U3.9
BATT+: J2.1, R1.1, U1.3, U2.1
GND: C1.2, C2.2, J1.2, J2.2, R2.2, U1.2, U1.4, U2.2, U2.4, U3.1, U3.10, U3.16
SENSE: R1.2, R2.1, U3.4
SOLAR+: J1.1, U1.1

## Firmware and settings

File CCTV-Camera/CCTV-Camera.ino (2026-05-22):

/*
 * CCTV-Camera — ESP32-CAM Node Firmware
 * ═══════════════════════════════════════════════════════════════════════════
 * Board  : AI-Thinker ESP32-CAM
 * Core   : esp32 by Espressif ≤ 1.0.6
 *
 * Before flashing each camera:
 *   → Open cam_config.h
 *   → Set CAM_ID (1–5) and CAM_NAME
 *   → Everything else (WiFi, server IP) stays the same
 *
 * Hardware wiring
 * ───────────────
 * SD card (1-bit MMC, no conflict with camera or flash LED)
 *   GPIO14 → CLK     GPIO15 → CMD     GPIO2 → DATA0
 *
 * Battery monitor (18650 via TP4056 solar charger)
 *   Batt+ → 100kΩ → GPIO33 → 100kΩ → GND
 *   GPIO33 = ADC1_CH5, works while WiFi active
 *
 * Network ports (per camera)
 * ──────────────────────────
 *   http://192.168.4.10x/        Per-camera debug UI
 *   http://192.168.4.10x:81/     MJPEG stream (consumed by RPi dashboard)
 *   http://192.168.4.10x/status  JSON status (polled by RPi dashboard)
 * ═══════════════════════════════════════════════════════════════════════════
 */

#include "cam_config.h"
#include "esp_camera.h"
#include <WiFi.h>
#include <WebServer.h>
#include "camera_pins.h"
#include "power.h"
#include "motion.h"
#include "recorder.h"
#include "webui.h"

WebServer  apiServer(80);
WiFiServer streamServer(81);

static void streamTask(void*) {
  for (;;) {
    WiFiClient c = streamServer.available();
    if (c) handleStreamClient(c);
    delay(10);
  }
}

void setup() {
  Serial.begin(115200);
  Serial.printf("\nCCTV-Camera %d (%s) starting...\n", CAM_ID, CAM_NAME);

  // Camera
  camera_config_t cfg = getCameraConfig();
  if (esp_camera_init(&cfg) != ESP_OK) {
    Serial.println("ERROR: camera init failed — check board selection");
    while (1) delay(1000);
  }

  // SD card (optional backup)
  if (!initSD()) Serial.println("No SD card — RPi-only recording");

  // Battery ADC
  initPower();

  // Connect to Raspberry Pi Access Point
  WiFi.mode(WIFI_STA);
  WiFi.config(CAM_STATIC_IP, CAM_GATEWAY, CAM_SUBNET, CAM_DNS);
  WiFi.begin(WIFI_SSID, WIFI_PASSWORD);

  Serial.printf("Connecting to %s as 192.168.4.%d", WIFI_SSID, 100 + CAM_ID);
  uint32_t t0 = millis();
  while (WiFi.status() != WL_CONNECTED) {
    if (millis() - t0 > 20000) { Serial.println("\nTimeout — restarting"); ESP.restart(); }
    Serial.print('.'); delay(500);
  }
  Serial.printf("\nOnline: http://%s\n", WiFi.localIP().toString().c_str());

  // Start servers
  setupWebServer(apiServer);
  apiServer.begin();
  streamServer.begin();

  // MJPEG stream runs on Core 0 (alongside WiFi stack)
  // API server + motion detection handle on Core 1 (loop)
  xTaskCreatePinnedToCore(streamTask, "stream", 8192, nullptr, 5, nullptr, 0);

  Serial.println("Ready.");
}

void loop() {
  apiServer.handleClient();
  updatePower();
  delay(5);
}

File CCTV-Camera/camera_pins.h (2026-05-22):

#pragma once
#include "esp_camera.h"

// AI-Thinker ESP32-CAM pin map
#define PWDN_GPIO_NUM   32
#define RESET_GPIO_NUM  -1
#define XCLK_GPIO_NUM    0
#define SIOD_GPIO_NUM   26
#define SIOC_GPIO_NUM   27
#define Y9_GPIO_NUM     35
#define Y8_GPIO_NUM     34
#define Y7_GPIO_NUM     39
#define Y6_GPIO_NUM     36
#define Y5_GPIO_NUM     21
#define Y4_GPIO_NUM     19
#define Y3_GPIO_NUM     18
#define Y2_GPIO_NUM      5
#define VSYNC_GPIO_NUM  25
#define HREF_GPIO_NUM   23
#define PCLK_GPIO_NUM   22

inline camera_config_t getCameraConfig() {
  camera_config_t c;
  memset(&c, 0, sizeof(c));
  c.ledc_channel = LEDC_CHANNEL_0;
  c.ledc_timer   = LEDC_TIMER_0;
  c.pin_d0       = Y2_GPIO_NUM;  c.pin_d1 = Y3_GPIO_NUM;
  c.pin_d2       = Y4_GPIO_NUM;  c.pin_d3 = Y5_GPIO_NUM;
  c.pin_d4       = Y6_GPIO_NUM;  c.pin_d5 = Y7_GPIO_NUM;
  c.pin_d6       = Y8_GPIO_NUM;  c.pin_d7 = Y9_GPIO_NUM;
  c.pin_xclk     = XCLK_GPIO_NUM;
  c.pin_pclk     = PCLK_GPIO_NUM;
  c.pin_vsync    = VSYNC_GPIO_NUM;
  c.pin_href     = HREF_GPIO_NUM;
  c.pin_sscb_sda = SIOD_GPIO_NUM;
  c.pin_sscb_scl = SIOC_GPIO_NUM;
  c.pin_pwdn     = PWDN_GPIO_NUM;
  c.pin_reset    = RESET_GPIO_NUM;
  c.xclk_freq_hz = 20000000;
  c.pixel_format = PIXFORMAT_JPEG;
  c.frame_size   = FRAMESIZE_VGA;   // 640×480 — RPi 4 handles this easily
  c.jpeg_quality = 10;              // 0–63, lower = better
  c.fb_count     = 2;
  return c;
}

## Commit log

2026-05-22 Initial commit: 6-camera CCTV system with adaptive RPi 4/5 support
    Components:
    - ESP32-CAM firmware (Arduino) with MJPEG streaming, motion detection,
    dual storage (RPi upload + SD card backup) for 6 cameras
    - RPi Flask server (cctv_server.py) with web dashboard, recordings browser,
    cleanup scheduler, retention estimator, /api/cameras endpoint
    - Adaptive install.sh: auto-detects RAM and picks LITE/MID/FULL mode,
    zram swap, systemd memory caps, RPi 5 fan curve
    - Native pygame HDMI display (display.py) for low-RAM boards (1 GB RPi)
    - Light-theme web dashboard with click-to-enlarge camera modal
    - Browser preview server (preview/) for design iteration on Windows
    - IP65 enclosure designs (Op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
    [cctv_enclosure.scad]
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2026-05-22 Remove ip65_box and ip65_lid (using commercial 140x78 box instead)
    User has a 140x78 mm waterproof junction box on hand, so the fully-printed
    enclosure parts are no longer needed. Removed:
    - ip65_box() function (FCMacro + scad)
    - ip65_lid() function (FCMacro + scad)
    - BOX_WALL_TH, BOX_LID_TH, GASKET_LIP, GASKET_RIM_W parameters
    - 'fully-printed' workflow text in build summary
    - PART switch entries for ip65_box / ip65_lid in scad
    Macro now creates exactly 6 parts that drop into the off-the-shelf box:
    1. electronics_tray
    2. tray_cover (snap-on, holds batteries + vents)
    3. camera_bezel (lens window + ESP32-CAM mount)
    4. lid_seal (TPU gasket)
    5. solar_bracket (adjustable tilt)
    6. wall_mount (b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
    [cctv_enclosure.scad]
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2026-05-22 Add proper ball-joint mounting: 2 sockets + redesigned solar_bracket
    Previously the wall_mount had a ball but no matching socket (it referred
    to a socket on the never-built printed box). The solar_bracket used a
    4-position tilt-lock, not a real ball joint.
    This change makes both mounts use a true ball joint, free to aim in any
    direction and locked by an M3 clamp screw:
    wall_mount + box_socket -> wall <-> IP65 camera box
    solar_bracket + panel_socket -> wall <-> solar panel
    New shared parameters at top of macro (used by all 4 mount parts):
    BALL_DIA = 20 mm
    STALK_DIA = 10 mm
    STALK_H = 15 mm
    Each socket has:
    - cylindrical cup with hollow spherical cavity (slip fit on ball)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
    [cctv_enclosure.scad]
2026-05-23 Fix SCAD render errors and sync naming/dims with FCMacro
    Bugs in the previous commit that prevented OpenSCAD from rendering:
    • box_socket() and panel_socket() both called _socket() — a function
    that does not exist. Correct name is _bottom_socket().
    • socket_top_half was defined but never wired into the PART dispatch
    or the "all" preview layout, so it was unreachable from the UI.
    Additional cleanup to keep SCAD and FCMacro in lockstep:
    • Renamed box_socket() → box_socket_bottom() (matches FCMacro)
    • Renamed panel_socket() → panel_socket_bottom() (matches FCMacro)
    • Synced plate dimensions:
    box_socket 55×45 → 60×50 mm (5 mm margin around 50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
    [cctv_enclosure.scad]
2026-05-23 Simplify enclosure: keep tray + flat wall plate, split into per-part files
    Removed parts: box_socket_bottom, panel_socket_bottom, socket_top_half,
    solar_bracket — these are no longer included.
    Remaining parts (2):
    1. Electronics tray — organises battery + MPPT + boost inside the IP65 box
    2. Wall mount plate — flat 80×80 mm plate; box attaches directly to front
    face with VHB tape or M3 screws (no ball joint)
    File split:
    enclosure/tray.scad — standalone, open in OpenSCAD → F6 → STL
    enclosure/wall_mount.scad — standalone, open in OpenSCAD → F6 → STL
    cctv_enclosure.scad — combined "all" preview, trimmed to 2 parts
    cctv_enclosure.FCMacro —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
    [cctv_enclosure.scad, tray.scad, wall_mount.scad]
2026-05-23 Swap wall mount for solar bracket (no ball); keep per-part file split
    Removed: enclosure/wall_mount.scad
    Added: enclosure/solar_bracket.scad
    Solar bracket geometry (standalone, no ball/stalk):
    - Vertical wall plate 25 × 4 × 100 mm — 2× M5 countersunk wall holes (z=15, 85)
    - Horizontal arm 25 × 80 × 4 mm — extends from top of plate
    - Triangular gusset — ties arm underside to plate
    - 4× M4 panel mounting holes (⌀4.5) — 2×2 grid near far end of arm
    Both standalone files remain self-contained (no includes):
    tray.scad — electronics tray (unchanged)
    solar_bracket.scad — new L-bracket
    cctv_enclosure.scad / .FCMacro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
    [cctv_enclosure.scad, solar_bracket.scad, wall_mount.scad]
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2026-05-23 Add 1S BMS clip to tray (DW01A+FS8205A, 20×10 mm)
    The previous design had no over-discharge protection — batteries could
    be permanently damaged after several cloudy days of insufficient solar.
    Changes:
    tray.scad / cctv_enclosure.scad / .FCMacro
    - New constant: BMS_W=20, BMS_D=10 (standard DW01A module)
    - New pcb_clip placed in the right column below MT3608:
    y = 4 + CN3791_D(20) + gap(5) + MT3608_D(17) + gap(5) = 51 mm
    - Clip outer ends at y=64.8 mm — fits within 68 mm tray depth
    - COL_X variable added for shared column X = 85 mm
    tray_layout.html
    - BMS shown in purple (rect 405,259 95×55 px)
    - Wiring channel extended to cover all 3 clips
    - Circu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
    [cctv_enclosure.scad, tray.scad]
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2026-06-01 Rearrange parts in CCTV_NodeV2 schematic for clearer routing
    - Move U5 OV7670 from (230,160) to (185,160) — 45mm closer to U4
    so the camera bus labels (SIOC/SIOD/VSYNC/HREF/PCLK/XCLK +
    CAM_D0..D7) span a much shorter visual distance.
    - Move R1/R2 4.7k pull-ups from (195,150)/(205,150) up to
    (130,130)/(135,130), placing them directly above U4 between the
    power chain and the MCU. Their tops connect to +3V3, bottoms to
    SIOD/SIOC respectively.
    - Fix label-position bug: R1/R2 had SIOD/SIOC on the wrong pin
    (top instead of bottom) and the +3V3 power flags weren't touching
    any pin tip. Now correctly wired: top pin to +3V3, bottom pin to
    the I2C signal.
    - Remove orphaned +3V3 label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
    [CCTV_NodeV2.kicad_sch]
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2026-06-01 Fix ESP32-S3-DevKitC-1 footprint: expand from 17 to 44 pins
    The real DevKitC-1 board has 22 pins per side (44 total) at 2.54mm
    pitch. The previous 17-pad version would physically not accept the
    module since 27 through-holes were missing.
    - Left column : 9 functional pads (1-9) + 13 NC pads (18-30)
    - Right column : 8 functional pads (10-17) + 14 NC pads (31-44)
    - Column span : unchanged at 22.86mm (x = ±11.43mm)
    - Pad positions: functional pads 1-17 unchanged — existing PCB traces
    remain valid
    - NC pads : fill out the full 22-pin column in both directions,
    2.54mm pitch, y = ±12.7 to ±27.94mm
    - Body outline : updated from ±13mm to ±28mm tall to repre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
2026-06-01 Fix OV7670_Module footprint: correct to narrow 2x9 dual-row header
    Previous version had pads in two widely-spaced single columns
    (x = ±10.16mm, 20.32mm apart) which does not match the physical
    OV7670 module connector.
    Correct layout: standard narrow 2x9 through-hole header
    - Left column x = -1.27mm : pads 1-9 (3V3,GND,RST,PWDN,SIOC,SIOD,VSYNC,HREF,PCLK)
    - Right column x = +1.27mm : pads 10-18 (XCLK,D7,D6,D5,D4,D3,D2,D1,D0)
    - Row pitch: 2.54mm, 9 rows from y=-10.16 to y=+10.16
    - Column spacing: 2.54mm centre-to-centre (total connector width 2.54mm)
    - Overall body outline: 6mm wide x 23.2mm tall
    - Pin 1 (3V3, top-left) marked with square pad + notch on silkscreen
    - All pin names on F.Fab l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
2026-06-01 Fix OV7670 pin numbering to match actual module (zigzag order)
    Previous versions used arbitrary sequential numbering that did NOT
    match the real OV7670 module. Corrected based on hardware datasheet.
    Correct pinout (2x9 zigzag, L=left col odd, R=right col even):
    Pin 1 (L) = SIOC Pin 2 (R) = SIOD
    Pin 3 (L) = VSYNC Pin 4 (R) = HREF
    Pin 5 (L) = PCLK Pin 6 (R) = XCLK
    Pin 7 (L) = D7 Pin 8 (R) = D6
    Pin 9 (L) = D5 Pin 10(R) = D4
    Pin 11(L) = D3 Pin 12(R) = D2
    Pin 13(L) = D1 Pin 14(R) = D0
    Pin 15(L) = RESET Pin 16(R) = PWDN
    Pin 17(L) = 3V3 Pin 18(R) = GND
    OV7670_Module.kicad_mod:
    - Pad positions unchanged (2x9, +-1.27mm columns, 2.54mm row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
    [CCTV_NodeV2.kicad_sch]
2026-06-01 Fix OV7670 pinout: 1=3V3, 2=GND, 3=SIOC ... 17=RESET, 18=PWDN
    Corrected to match actual module datasheet (androiderode.com pinout):
    Pin 1 (L row1) = 3V3 Pin 2 (R row1) = GND
    Pin 3 (L row2) = SIOC Pin 4 (R row2) = SIOD
    Pin 5 (L row3) = VSYNC Pin 6 (R row3) = HREF
    Pin 7 (L row4) = PCLK Pin 8 (R row4) = XCLK
    Pin 9 (L row5) = D7 Pin 10 (R row5) = D6
    Pin 11 (L row6) = D5 Pin 12 (R row6) = D4
    Pin 13 (L row7) = D3 Pin 14 (R row7) = D2
    Pin 15 (L row8) = D1 Pin 16 (R row8) = D0
    Pin 17 (L row9) = RESET Pin 18 (R row9) = PWDN
    Previous incorrect version (last commit) had 3V3 at pin 17, SIOC
    at pin 1. This version is now corr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
    [CCTV_NodeV2.kicad_sch]
2026-06-01 Fix ESP32-S3-DevKitC-1 layout to match physical board (OceanLabz pinout)
    Footprint (ESP32-S3-DevKitC-1.kicad_mod):
    44 pads at correct physical y-positions (2.54mm pitch, y=-27.94 to +25.40)
    Left col pads 1-22 (x=-11.43):
    1=3V3, 2=3V3, 3=RST, 4=GPIO4, 5=GPIO5, 6=GPIO6, 7=GPIO7,
    8=GPIO15, 9=GPIO16, 10=GPIO17, 11=GPIO18, 12=GPIO8, 13=GPIO3,
    14=GPIO46, 15=GPIO9, 16=GPIO10, 17=GPIO11, 18=GPIO12, 19=GPIO13,
    20=GPIO14, 21=5V0, 22=GND
    Right col pads 23-44 (x=+11.43):
    23=GND, 24=GPIO43, 25=GPIO44, 26=GPIO1, 27=GPIO2, 28=GPIO42,
    29=GPIO41, 30=GPIO40, 31=GPIO39, 32=GPIO38(RGB), 33=GPIO37,
    34=GPIO36, 35=GPIO35, 36=GPIO0(BOOT), 37=GPIO45, 38=GPIO48,
    39=GPIO47, 40=GPI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
    [CCTV_NodeV2.kicad_sch]
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2026-06-01 Fix BMS → MT3608 power path: add P+ net, remove BATT+ bypass
    The MT3608 boost converter was incorrectly connected directly to the
    BATT+ net (raw battery positive), bypassing the 1S BMS protection.
    Correct power flow (battery → BMS → MT3608 → 5V → ESP32):
    Battery J2 + → BATT+ → BMS B+ (cell side, charging via CN3791)
    BMS P+ output → P+ → MT3608 IN+ (protected, load side)
    BMS P- output → PROT- → MT3608 IN- (already correct)
    Schematic (CCTV_NodeV2.kicad_sch):
    - Removed stray BATT+ power flag at MT3608 IN+ (167.3, 64.92)
    - Renamed net label at BMS P+ pin (142.7, 64.92): BATT+ → P+
    - Renamed net label at MT3608 IN+ pin (167.3, 64.92): BATT+ → P+
    PCB (CCT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
    [CCTV_NodeV2.kicad_pcb, CCTV_NodeV2.kicad_sch]
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2026-06-01 Move CN3791 pads to module PCB edges (x=+-20mm from centre)
    Footprint (CN3791_Module.kicad_mod):
    - Pads moved from x=+-18mm to x=+-20mm (1.5mm inside the +-21.5mm
    PCB edge) so they sit visually at the short sides of the module PCB
    - Pin labels (IN+/IN-/BAT+/BAT-) shifted outward to match
    - Pin 1 marker '1' moved to x=-24 (outside the PCB outline)
    PCB (CCTV_NodeV2.kicad_pcb) — U1 CN3791 pad positions updated:
    Pad 1 (IN+ / SOLAR+): was (-8.89,-1.27) → now (-20,-2.5)
    Pad 2 (IN- / SOLAR-): was (-8.89, 1.27) → now (-20, 2.5)
    Pad 3 (BAT+ / BATT+): was ( 8.89,-1.27) → now ( 20,-2.5)
    Pad 4 (BAT- / BATT-): was ( 8.89, 1.27) → now ( 20, 2.5)
    Net assignments and UUIDs unchan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
    [CCTV_NodeV2.kicad_pcb]
2026-06-01 Redesign CN3791 footprint: single-row 4-hole + correct pinout
    Physical module has 4 holes in a single row (not 2x2), labelled
    left-to-right: VIN | GND | GND | BAT
    CN3791_Module.kicad_mod (footprint):
    - Changed from wide 2x2 layout (x=+-20mm) to single row
    - 4 pads at 2.54mm pitch: x = -3.81, -1.27, +1.27, +3.81, all y=0
    - PCB outline: 35x17mm body on F.Fab + F.SilkS
    - Courtyard: 36.4x18.4mm
    - Silk labels: VIN / GND / GND / BAT above each pad
    - Pin 1 marker + orientation notch top-left
    - CN3791 IC body placeholder + LED circle on F.Fab
    CCTV_NodeV2.kicad_sch (schematic symbol fix):
    - CN3791 pin 3 was B+/BAT+ → now GND (physical pad 3 = GND)
    - CN3791 pin 4 was B-/BAT- → now BAT+ (physical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
    [CCTV_NodeV2.kicad_pcb, CCTV_NodeV2.kicad_sch]
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2026-06-01 Update CN3791 embedded PCB geometry to 45x20mm
    The .kicad_pcb file caches footprint geometry at embed-time, so
    the old 23x11mm body outline was still showing in pcbnew despite
    the .kicad_mod file being corrected.
    Replaced the entire CN3791 body block in CCTV_NodeV2.kicad_pcb:
    Old body: (-11.5,-5.5) to (+11.5,+5.5) = 23mm x 11mm
    New body: (-22.5,-10) to (+22.5,+10) = 45mm x 20mm ✓
    Also added:
    F.Fab outline (same rect, 45x20mm)
    F.CrtYd: (-23.2,-10.7) to (+23.2,+10.7) = 46.4x21.4mm
    Orientation notch (top-left corner lines)
    IC body box (-7,-5) to (+7,+5)
    LED circle at (17,-6)
    VIN/GND/GND/BAT silk labels above pads
    Pad size/drill updated: 2.0mm / 1.2mm drill
    [CCTV_NodeV2.kicad_pcb]
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2026-06-02 Replace U2 BMS from DW01A+FS8205A to TC4056A_BMS_Module
    Replaces the standalone 1S BMS (DW01A + FS8205A) with the TC4056A
    combined USB charger + BMS protection module on U2.
    - Added CCTV2:TC4056A_BMS lib symbol (6 pins):
    Pin 1 = IN+ (USB 5V charging input) → NC marker
    Pin 2 = IN- (USB GND) → GND symbol
    Pin 3 = B+ (battery positive) → BATT+ (same position as old BMS pin1)
    Pin 4 = B- (battery negative) → BATT-/GND (same position as old BMS pin2)
    Pin 5 = OUT+ (BMS protected output +) → P+ (same position as old BMS pin3)
    Pin 6 = OUT- (BMS protected output -) → PROT- (same position as old B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
    [CCTV_NodeV2.kicad_pcb, CCTV_NodeV2.kicad_sch]
2026-06-02 Fix U3 MT3608 pad 4: remove '+5V_GND' net, correct to GND
    OUT- of a boost converter is the output return path = GND.
    A net label '+5V_GND' had been placed at the MT3608 OUT- pin
    position (192.7, 75.08) in the schematic, causing KiCad to create
    a merged '/+5V_GND' net that incorrectly tied the +5V and GND
    buses together on pad 4.
    - Deleted stray net label '+5V_GND' at (192.7, 75.08)
    - The GND power symbol already present at (192.7, 76.35)
    connects OUT- to GND correctly — no replacement needed
    PCB (CCTV_NodeV2.kicad_pcb):
    - U3 pad 4 (OUT-): net '/+5V_GND' → 'GND'
    - This removes the short circuit between +5V and GND on U3
    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
    [CCTV_NodeV2.kicad_pcb, CCTV_NodeV2.kicad_sch]
2026-06-02 Fix U3 MT3608 pad 4 (OUT-): GND → PROT- (same node as pad 2 IN-)
    Pad 2 (IN-) and pad 4 (OUT-) of the MT3608 module are connected
    together on the module's internal copper pour — they are the SAME
    electrical node. Both must be on the PROT- net so the BMS can
    actually cut off the load when over-discharge occurs.
    Previously pad 4 was changed to GND in the last commit, which would
    have shorted the BMS protection FETs (PROT- → GND directly) and
    made the DW01A protection circuit useless.
    Correct circuit:
    Battery B- → BMS B- → [DW01A FETs] → PROT- → MT3608 pad2(IN-)
    ↕ (same node on module PCB)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
    [CCTV_NodeV2.kicad_pcb, CCTV_NodeV2.kicad_sch]
2026-06-02 Fix TC4056A BMS footprint: 4 pads at BOTTOM EDGE, 4-pin symbol
    Physical module (from image): 26x17mm PCB, USB-C charging at top,
    4 through-hole solder pads at the BOTTOM EDGE (not in the middle).
    Pad order left-to-right: OUT- | B- | B+ | OUT+
    TC4056A_BMS_Module.kicad_mod:
    - Removed 6 centre pads (IN+/IN- are USB-C handled internally)
    - 4 pads repositioned at bottom edge y=+7.5:
    Pad 1 (OUT-/PROT-) : x=-6.75 [square, pin 1 marker]
    Pad 2 (B- /BATT-) : x=-2.25
    Pad 3 (B+ /BATT+) : x=+2.25
    Pad 4 (OUT+/P+) : x=+6.75
    - USB-C placeholder at top, IC boxes, LED circles on F.Fab
    - Pad spacing ~4.5mm (verify against your specific module)
    CCTV_NodeV2.kicad_sch:
    - TC4056A_BMS symbol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
    [CCTV_NodeV2.kicad_pcb, CCTV_NodeV2.kicad_sch]
2026-06-02 Redesign TC4056A footprint to match actual module (2+4 pad layout)
    Physical layout from image:
    LEFT edge : USB-C connector + 2 pads
    pad 1 = IN+ (top, square)
    pad 2 = IN- (bottom)
    RIGHT edge: 4 pads at 2.54mm pitch
    pad 3 = OUT+ (top)
    pad 4 = B+
    pad 5 = B-
    pad 6 = OUT- (bottom)
    PCB body: 36mm wide x 22mm tall
    - Body: (-18,-11) to (+18,+11) = 36x22mm
    - USB-C placeholder on left, IC boxes on centre-right
    - Left edge pads: 1(IN+,rect,top) at (-17,-5.5), 2(IN-,circ) at (-17,+5.5)
    - Right edge pads: 3(OUT+) at (+17,-3.81), 4(B+) at (+17,-1.27),
    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
    [CCTV_NodeV2.kicad_pcb, CCTV_NodeV2.kicad_sch]
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2026-06-02 Move all wiring labels/power symbols with U4 and U5
    All net labels, power symbols (+5V, +3V3, GND) and R1/R2 pull-up
    resistors have been relocated to the correct new pin positions.
    Because the ESP32-S3 symbol was redesigned with physical pin ordering
    (44 pins, new y-coordinates per pin), labels could NOT simply shift
    by a fixed offset — each needed its own target y calculated as:
    new_y = placed_y(220) − symbol_pin_y
    U4 (60, 220) — left column labels now at x=42.22:
    +5V → (42.22, 197.14) [pin 21]
    GND → (42.22, 194.60) [pin 22]
    +3V3 → (42.22, 247.94) [pin 1]
    SIOD → (42.22, 240.32) [pin 4 GPIO4]
    SIOC → (42.22, 237.78) [pin 5 GPIO5]
    VSYNC → (42.22, 2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
    [CCTV_NodeV2.kicad_sch]
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2026-06-02 Fix U4/U5 label angles: 0→180 so text renders outside body
    Net labels at x=42.22 (U4 left pins) and x=272.22 (U5 left pins)
    had angle=0, which in KiCad renders text to the RIGHT of the anchor
    point — directly into the component body (body starts at x=44.76
    and x=274.76 respectively).
    Changed all net labels at those x positions from angle=0 to angle=180
    so text extends LEFT (away from the body). 23 labels updated.
    Power symbols (+5V, +3V3, GND) at the same x positions were NOT
    changed — they use symbol-level rotation which is different from
    label angle, and their small visual footprint does not overlap the
    body.
    [CCTV_NodeV2.kicad_sch]
2026-06-02 Separate R1 and R2 vertically to prevent overlap
    Both resistors were at y=232 (same height, x=20 and x=25) — only
    5mm apart, causing heavy visual overlap in eeschema.
    R1 (SIOD 4.7k pull-up) moved: y=232 → y=244
    Centre : (20,232) → (20,244)
    Ref/Value : (23,232/235) → (23,244/247)
    +3V3 flag : (20,228.19) → (20,240.19)
    SIOD label : (20,235.81) → (20,247.81)
    R2 (SIOC 4.7k pull-up) stays at y=232:
    Centre (25,232), +3V3 (25,228.19), SIOC label (25,235.81)
    Vertical gap R2-bottom to R1-top: 235.81 → 240.19 = 4.4mm
    Centre-to-centre separation: 12mm
    [CCTV_NodeV2.kicad_sch]
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2026-06-03 Fix unconnected U4 pin 17 (CAM_D0) — move label to wire endpoint
    The CAM_D0 label near U4 was at (57.15, 137.16) but the wire
    from U4 pin 17 ends at (58.73, 137.45) — a small gap causing
    ERC 'pin unconnected' error.
    Connection chain after fix:
    U4 pin 17 (GPIO11_D0) at (66.04, 137.16)
    → wire → (58.73, 137.45)
    ← label 'CAM_D0' ← (moved from 57.15,137.16)
    → connects by name to →
    U5 pin 16 (D0) label 'CAM_D0' at (173.99, 157.48) ✓
    [CCTV_NodeV2.kicad_sch]
2026-06-03 Fix all U4 label gaps — move labels to wire endpoints
    All U4 pin wires run from pin endpoint (66.04, y_pin) to
    (58.73, y_pin+0.29). Labels were at either x=57.15 (wrong x
    and wrong y) or x=61.27 (wrong x, correct y), causing
    'pin unconnected' ERC errors on every U4 signal pin.
    Fixed 15 positions by moving all labels to (58.73, y_wire_end):
    x=57.15 labels (CAM signals + power):
    CAM_D7 : (57.15,157.48) → (58.73,157.77)
    CAM_D6 : (57.15,154.94) → (58.73,155.23)
    CAM_D5 : (57.15,152.40) → (58.73,152.69)
    CAM_D2 : (57.15,149.86) → (58.73,150.15)
    CAM_D1 : (57.15,142.24) → (58.73,142.53)
    CAM_D3 : (57.15,139.70) → (58.73,139.99)
    CAM_D4 : (57.15,134.62) → (58.73,134.91)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
    [CCTV_NodeV2.kicad_sch]
2026-06-03 Connect U5 OV7670 pin17 RESET to +3V3 and pin18 PWDN to GND
    Pins 17 (RESET) and 18 (PWDN) were unconnected, which causes the
    OV7670 sensor to behave unpredictably:
    - RESET floating → spurious resets or sensor stuck in reset
    - PWDN floating → sensor may enter power-down randomly
    Correct connections for normal operation:
    Pin 17 RESET (138.43, 144.78) → +3V3 (active-low reset, HIGH = run)
    Pin 18 PWDN (138.43, 147.32) → GND (active-high power-down, LOW = run)
    Added two power symbols at the pin endpoints.
    [CCTV_NodeV2.kicad_sch]
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2026-06-03 Fix U4 right-column GND pads 23/43/44 net in PCB
    PCB had these pads on auto-generated 'unconnected-...' nets
    because the schematic GND symbols were added after the last F8 sync.
    Updated net assignments directly:
    Pad 23 (GND_R) : unconnected-(U4-GND_R-Pad23) → GND
    Pad 43 (GND_R2) : unconnected-(U4-GND_R2-Pad43) → GND
    Pad 44 (GND_R3) : unconnected-(U4-GND_R3-Pad44) → GND
    Pad 22 (left col GND) was already GND ✓
    [CCTV_NodeV2.kicad_pcb]
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2026-06-03 Remove stray GND symbol under U3 MT3608 pin 2 (IN-)
    A GND power symbol at (167.3, 76.35) was sitting 1.27mm below
    U3 pin 2 (IN-) at (167.3, 75.08). Pin 2 is correctly connected
    to PROT- (the BMS protected output negative) via a net label.
    The stray GND symbol was a leftover from an earlier incorrect
    version where pin 2 was wired to raw GND instead of PROT-.
    Leaving it would short PROT- to GND, completely bypassing the
    BMS over-discharge protection.
    After fix:
    U3 pin 2 (IN-) at (167.3, 75.08) → label 'PROT-' only ✓
    No GND connection on U3 pin 2
    [CCTV_NodeV2.kicad_sch]
2026-06-03 Delete 3 stray GND symbols beside U1 and U2
    Removed floating GND power symbols that were sitting ~1.27mm
    below component pins which already had correct net labels.
    These could cause unintended net merges in KiCad ERC.
    Deleted:
    GND at (67.3, 76.35) — beside U1 CN3791 pin2 (SOLAR- label)
    GND at (117.3, 76.35) — beside U2 TC4056A left pins (BATT- label)
    GND at (142.7, 76.35) — beside U2 TC4056A pin6 (PROT- label) ← DANGEROUS:
    would short PROT- to GND, bypassing BMS
    Kept (legitimate):
    GND at (117.3, 60.65) — U2 pin2 IN- intentional GND connection
    All U4/U5 GND connections
    [CCTV_NodeV2.kicad_sch]
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2026-06-03 Save PCB layout, project settings and DRC report
    - PCB layout updated in pcbnew (component placement, footprint
    refreshes, routing changes)
    - Project settings updated: min_text_height 0.8→0.5mm (resolved
    silk text height DRC warnings), min_via_diameter 1.0→0.6mm
    KiCad/DRC.rpt:
    - Updated DRC report from latest run
    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
    [CCTV_NodeV2.kicad_pcb]
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2026-06-13 KiCad: clean up U5 (OV7670) symbol/footprint + convert U4 to 40-pin
    U5 OV7670 symbol: redrawn to match the module silkscreen (pins renamed
    3.3V/SCL/VS/PLK/D7.../DGND/SDA/HS/XLK..., then re-laid into a single
    left-hand column in connector order 1-18). Power-symbol net-name text
    repositioned so it no longer overlaps the signal labels.
    U5 footprint on PCB: moved the 2x9 header to the left of the lens (matching
    the photo) by translating the pads -34mm; old/dangling routing ripped up
    (U5 now unrouted, ratsnest ready to re-route). Pin numbering/nets unchanged.
    U4 ESP32-S3: converted the 44-pin (2x22) symbol to a clean 40-pin (2x20).
    Dropped the 4 padless duplicate power pins (2/22/23/44) and ren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
    [CCTV_NodeV2.kicad_pcb, CCTV_NodeV2.kicad_sch]
